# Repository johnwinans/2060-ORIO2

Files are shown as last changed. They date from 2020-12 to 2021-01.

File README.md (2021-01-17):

# ORIO2
Open Robot IO Controller Version 2 Rev 2.

A [PDF of the schematic can be found here](2060-ORIO2.pdf).

This project contains 
[KiCad 5](https://kicad.org/) 
design files for a 
[Rasbperry PI](https://www.raspberrypi.org/products/)
add-on module that can be used to operate a robot such as those used in 
[First Robotics Competition](https://www.firstinspires.org/robotics/frc).

The ORIO2 adds the following I/O ports to a Raspberry PI:

* 10 5V tolerant LVTTL quadrature inputs with 3.3v or 5v power
* 8 5V tolerant LVTTL digital inputs with 3.3v or 5v power
* 8 LVTTL digital outputs with 3.3v or 5v power
* 16 direct-FPGA GPIO pins on header with 3.3v power
* 1 Power LED
* 8 User LED outputs
* 8 User switch (binary inputs)
* 2 User push-button (binary inputs)
* 8 ADC inputs 0-5V (w/jumper on port 0 to monitor battery voltage)
* 16 PWM outputs w/6V, 3A power
* 1 12V RSL light output
* 8 24V solenoid outputs
* 1 12V air-compressor relay control output
* 1 Raspberry PI I2C pinout with 3.3V power supply & pullup resistors

All I/O is controlled with a Lattice ICE40HX4K-TQ144 FPGA that 
communicates with the PI using the PI's SPI port.

The FPGA and Raspberry PI source code is open-source and managed 
using a github repo here: 
[ORIO2-software](https://github.com/johnwinans/ORIO2-software)

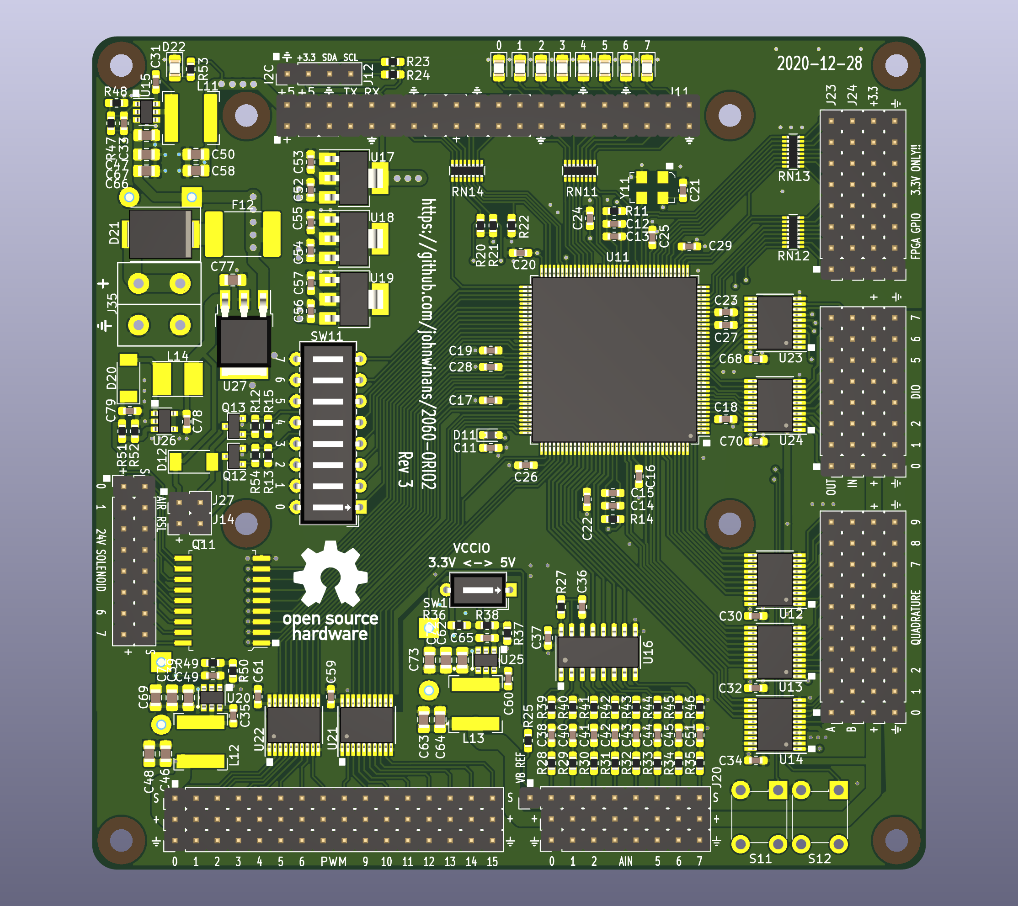
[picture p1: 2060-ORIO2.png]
PCB Image


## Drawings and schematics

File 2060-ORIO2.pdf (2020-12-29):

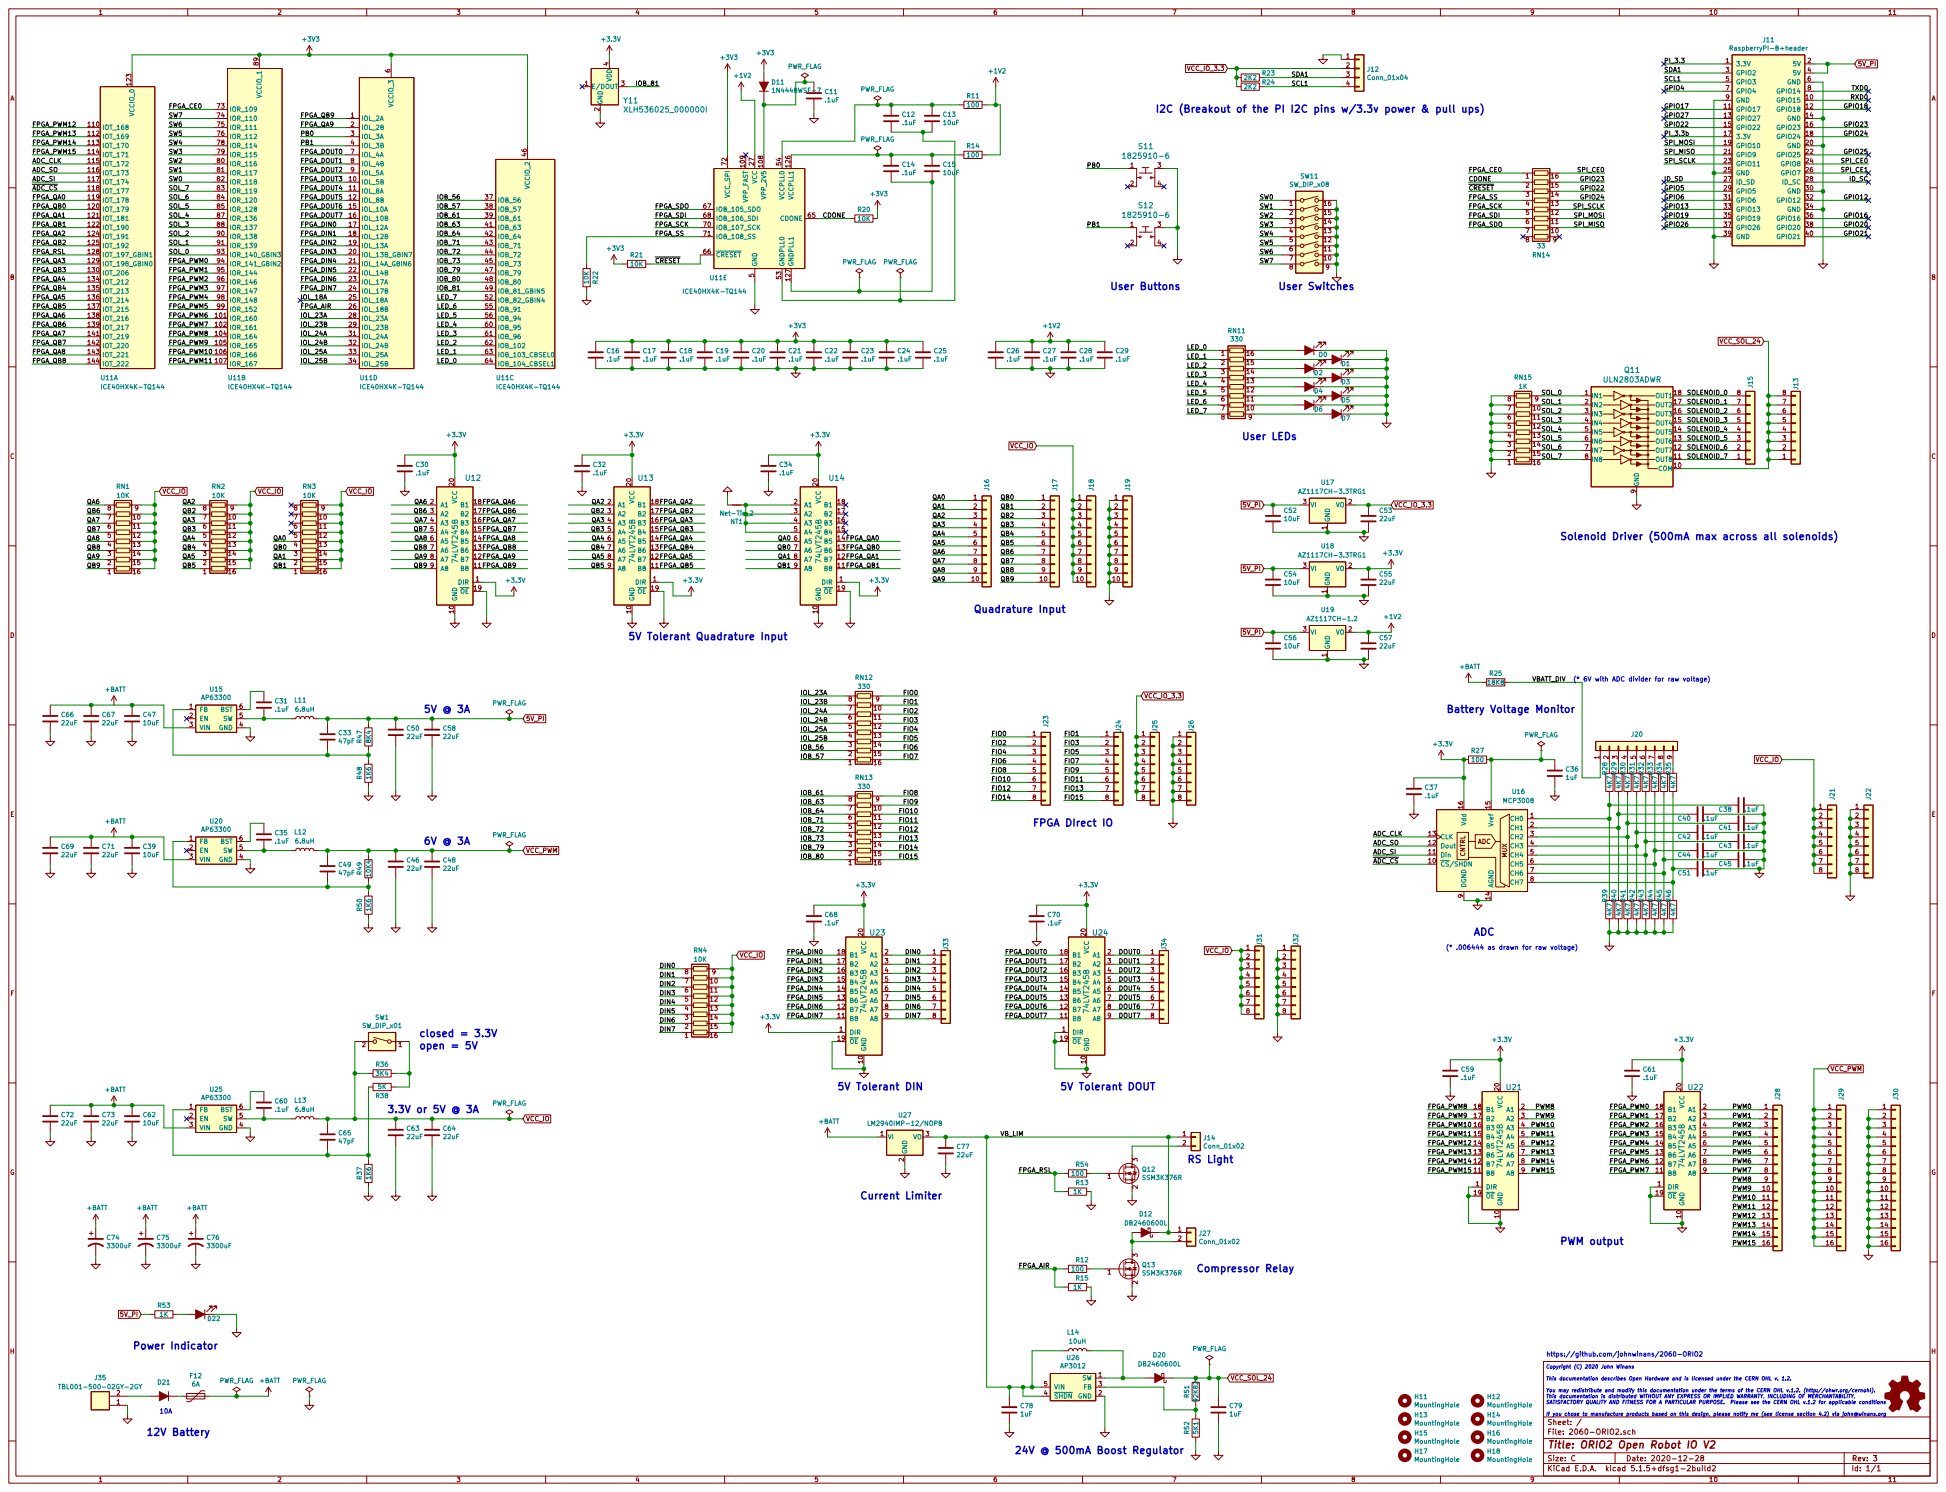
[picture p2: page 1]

I2C (Breakout of the PI I2C pins w/3.3v power & pull ups)

Solenoid Driver (500mA max across all solenoids)

(* 6V with ADC divider for raw voltage)

(* .006444 as drawn for raw voltage)

If you chose to manufacture products based on this design, please notify me (see license section 4.2) via john@winans.org Power Indicator

https://github.com/johnwinans/2060-ORIO2

Copyright (C) 2020 John Winans This documentation describes Open Hardware and is licensed under the CERN OHL v. 1.2. You may redistribute and modify this documentation under the terms of the CERN OHL v.1.2. (http://ohwr.org/cernohl). This documentation is distributed WITHOUT ANY EXPRESS OR IMPLIED WARRANTY, INCLUDING OF MERCHANTABILITY, SATISFACTORY QUALITY AND FITNESS FOR A PARTICULAR PURPOSE. Please see the CERN OHL v.1.2 for applicable conditions

H12 MountingHole H14 MountingHole H16 MountingHole H18 MountingHole

File: 2060-ORIO2.sch Sheet: /
Id: 1/1 Title: ORIO2 Open Robot IO V2

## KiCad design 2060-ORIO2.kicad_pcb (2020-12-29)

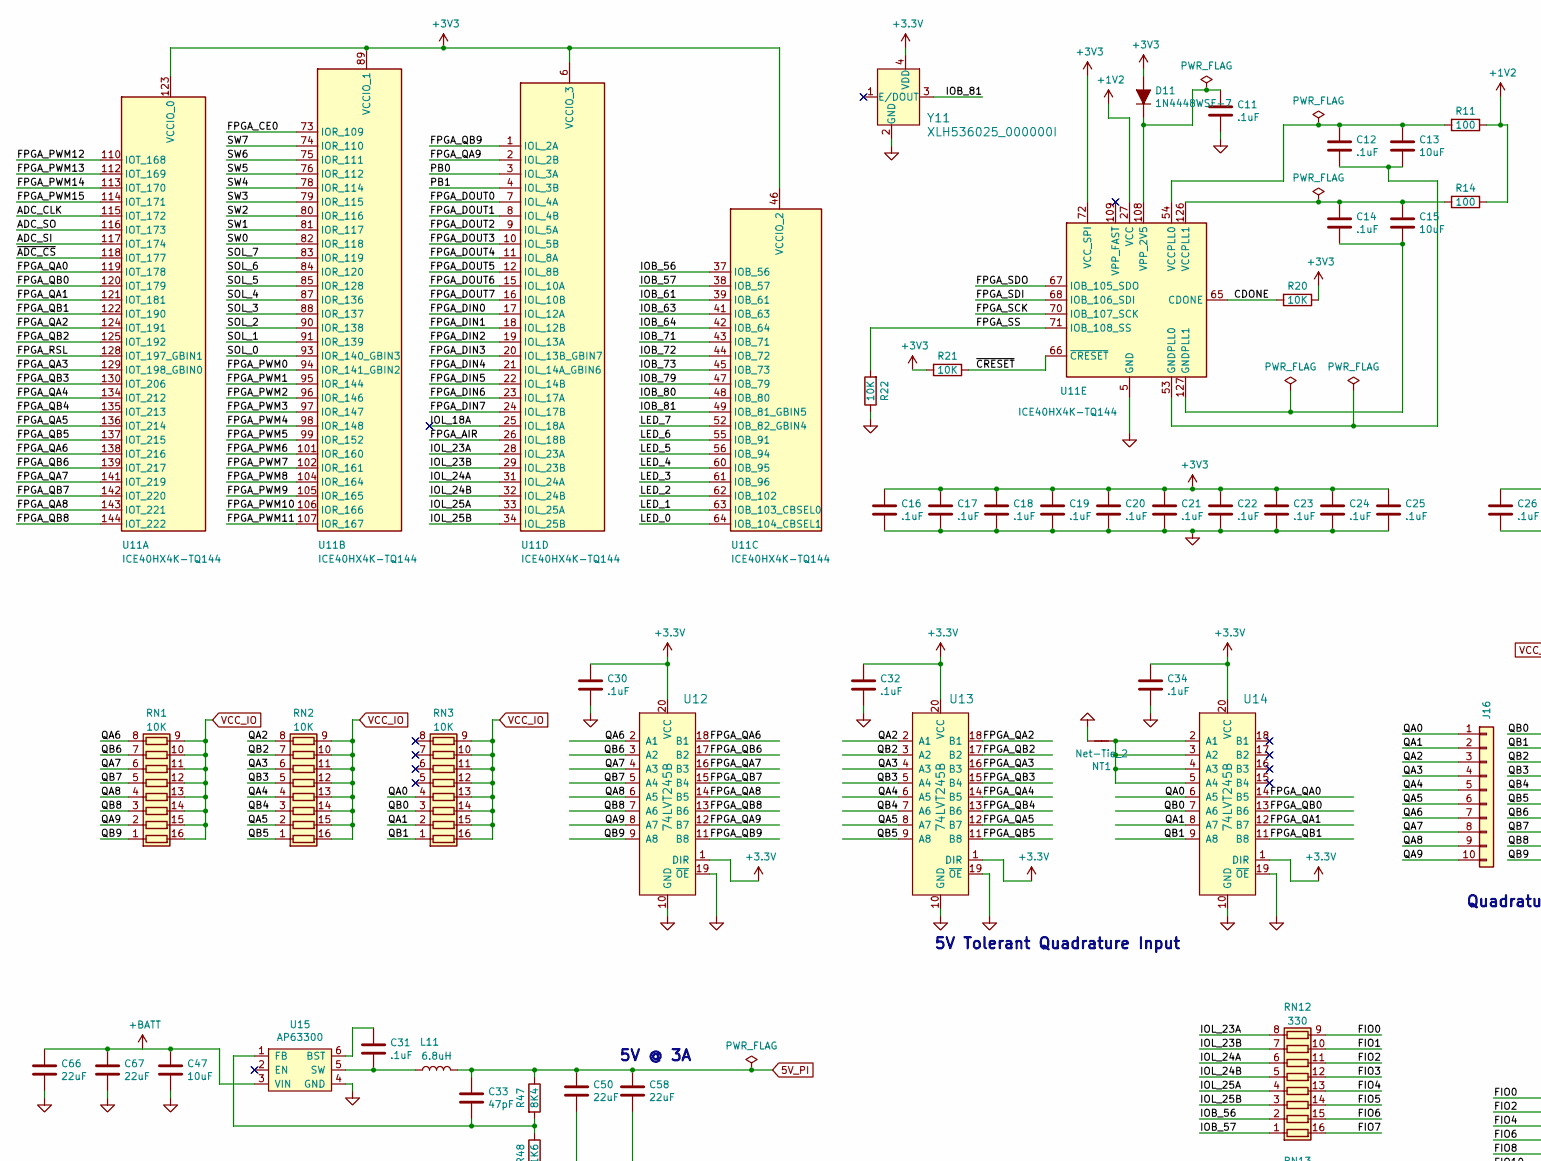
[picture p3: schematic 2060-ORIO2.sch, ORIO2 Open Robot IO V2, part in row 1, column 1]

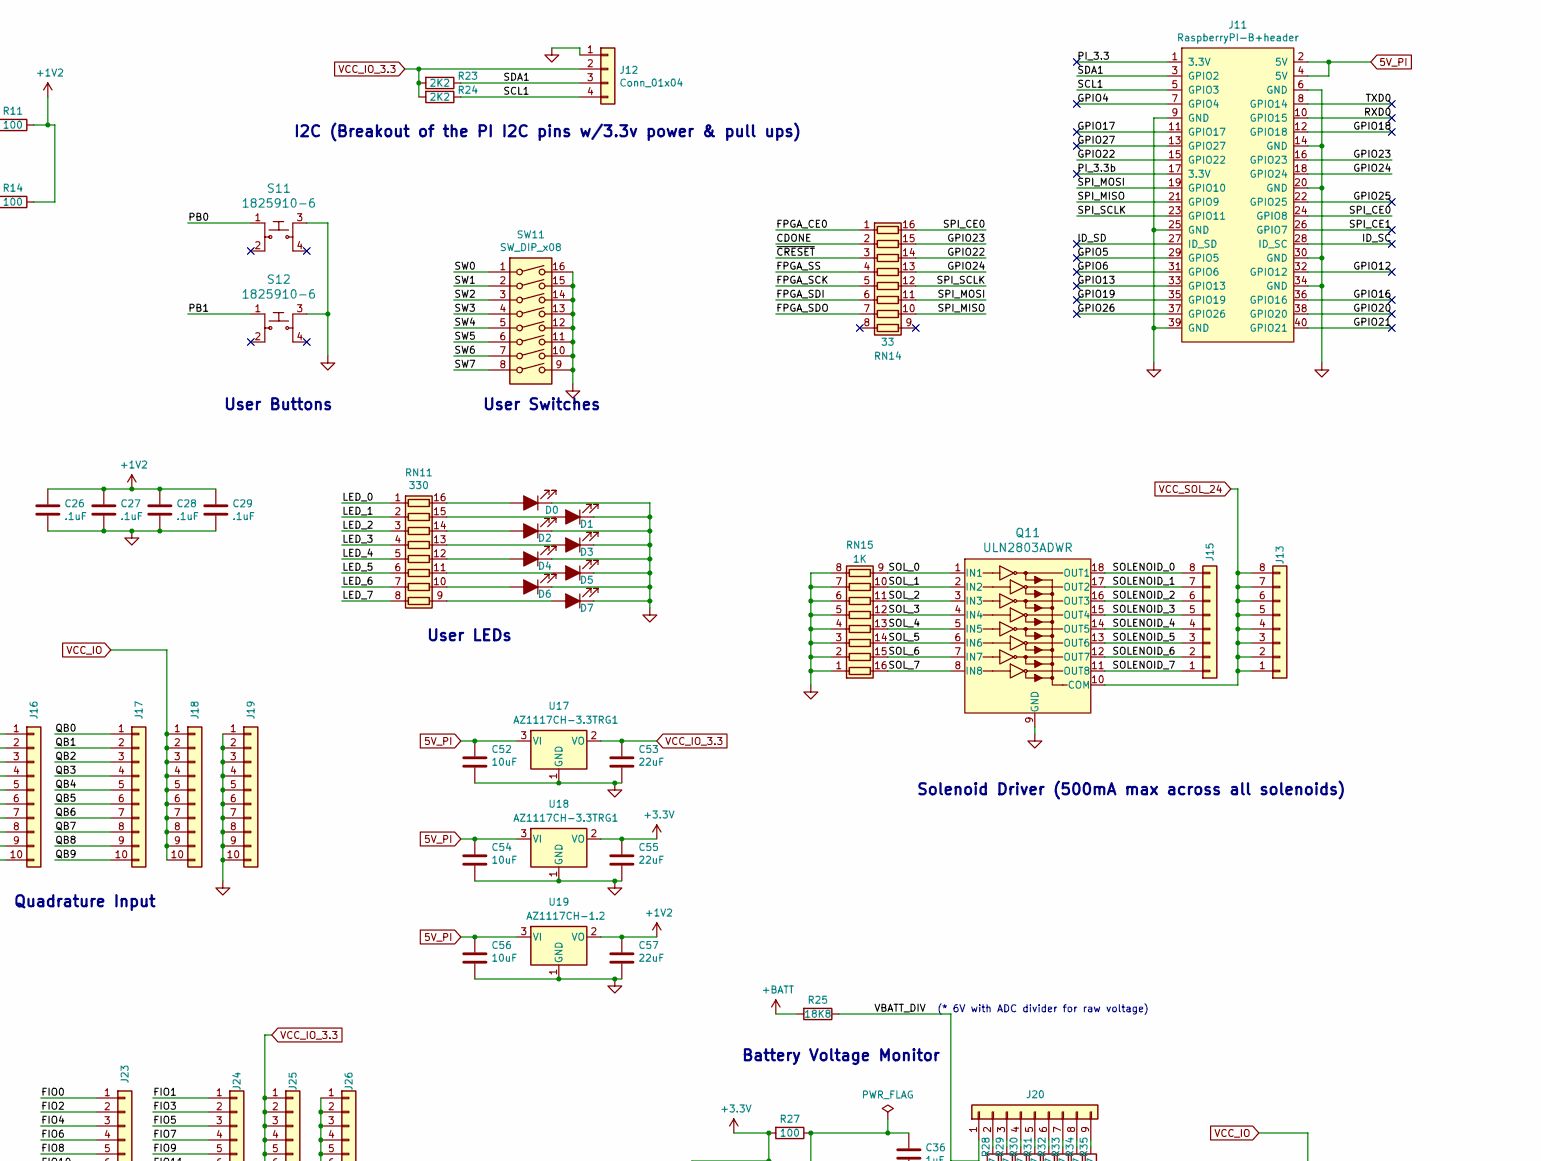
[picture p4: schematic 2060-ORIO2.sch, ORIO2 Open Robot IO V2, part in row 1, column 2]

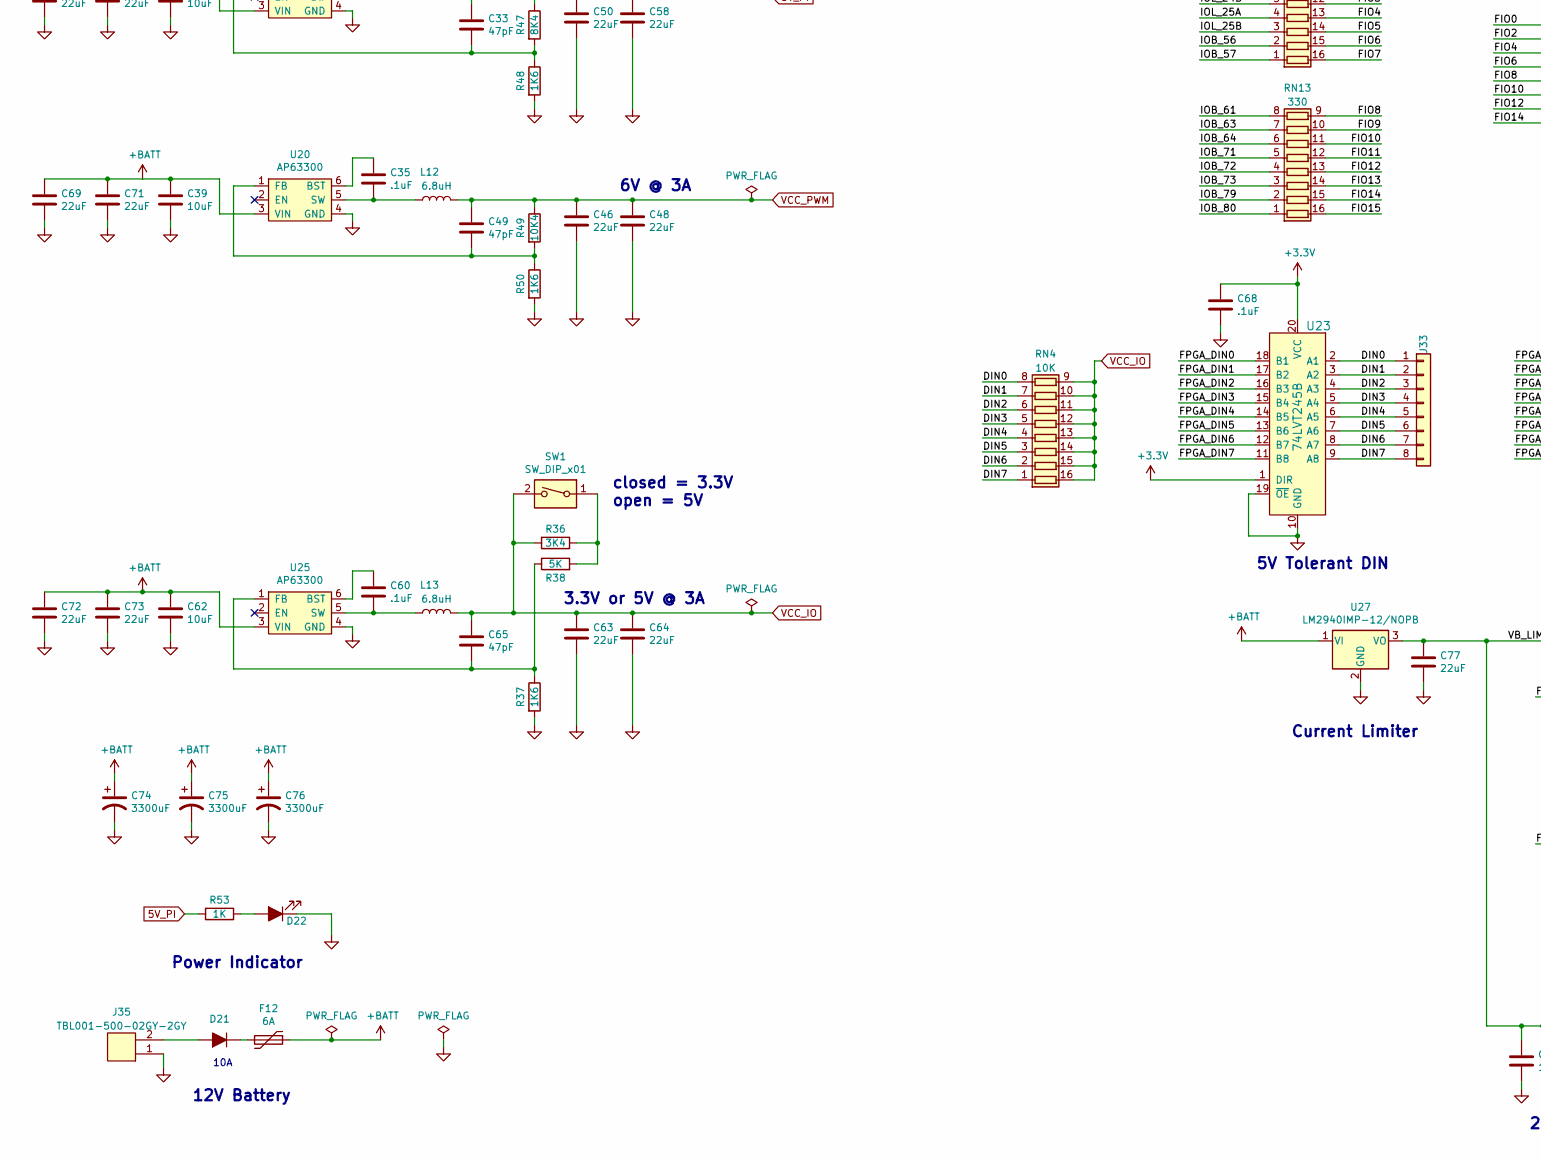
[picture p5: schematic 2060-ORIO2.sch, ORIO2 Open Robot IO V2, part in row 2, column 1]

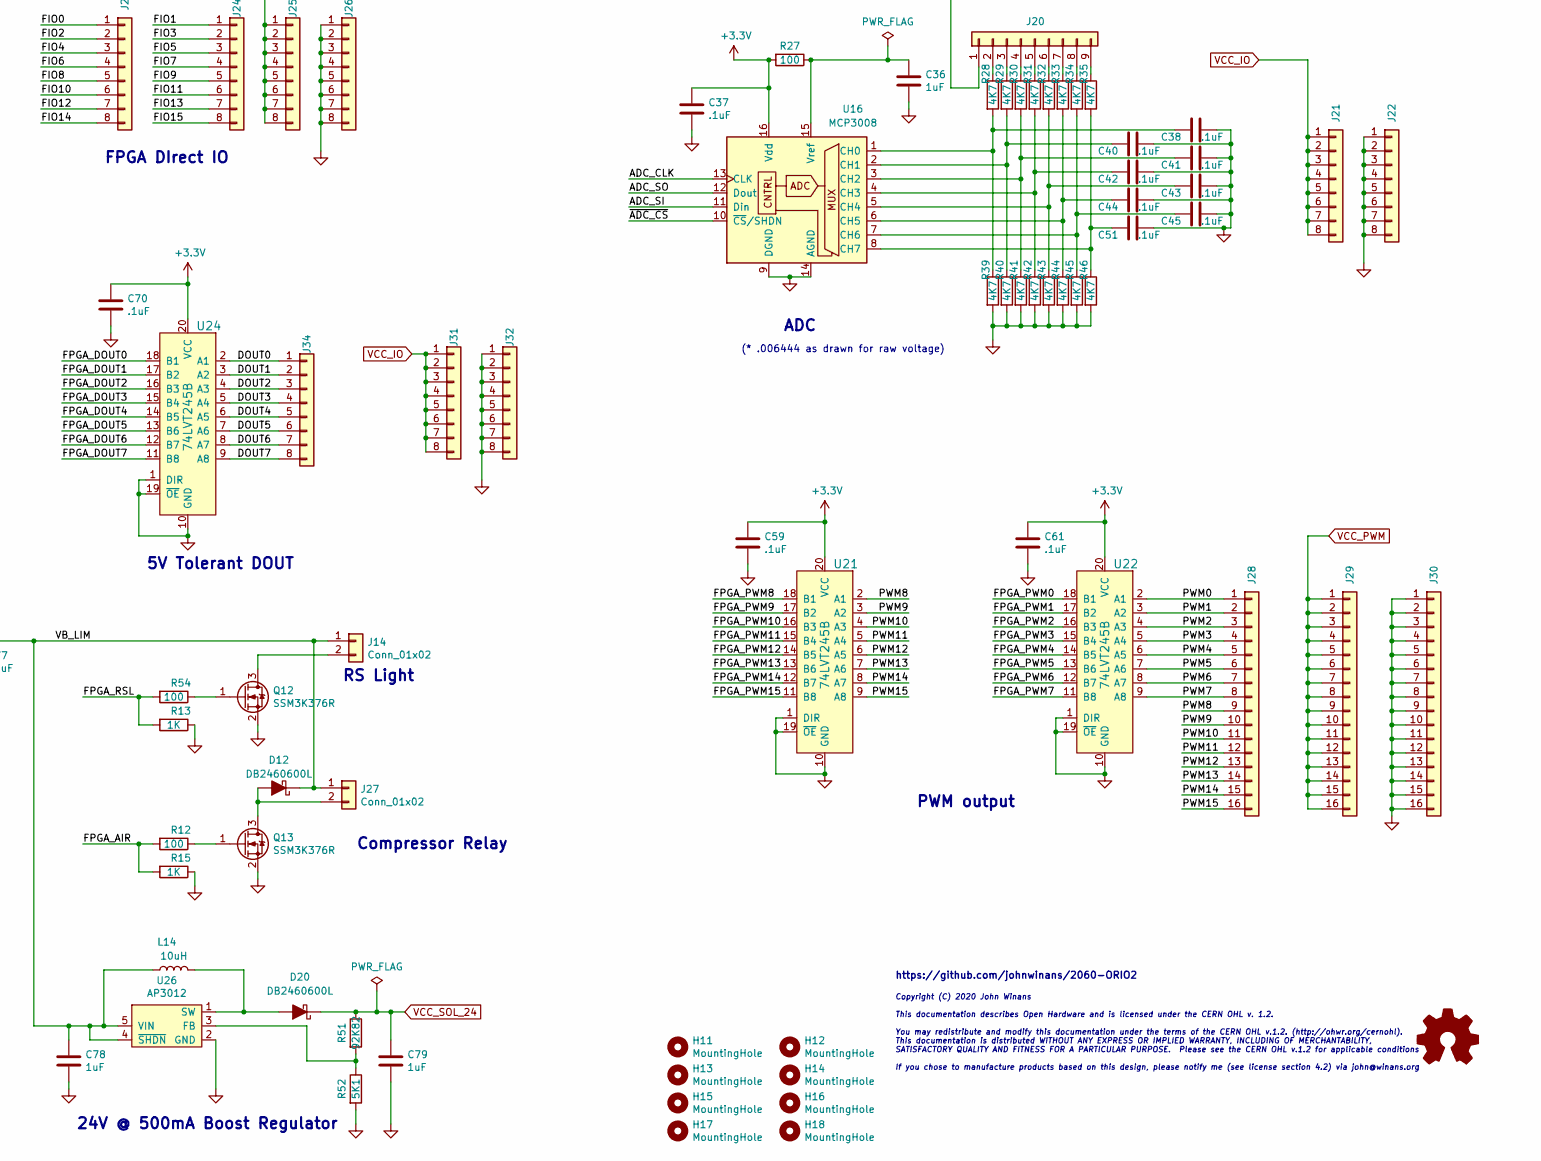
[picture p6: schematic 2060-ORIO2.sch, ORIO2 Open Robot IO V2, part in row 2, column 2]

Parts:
C11, C12, C14, C16, C17, C18, C19, C20, C21, C22, C23, C24, C25, C26, C27, C28, C29, C30, C31, C32, C34, C35, C37, C38, C40, C41, C42, C43, C44, C45, C51, C59, C60, C61, C68, C70: .1uF; C_0603_1608Metric_Pad1.05x0.95mm_HandSolder; MPN C1608X5R1E104K; Digi-Key_PN 445-6854-1-ND
C13, C15, C52, C54, C56: 10uF; C_0603_1608Metric_Pad1.05x0.95mm_HandSolder; MPN CL10A106MQ8NNNC; Digi-Key_PN 1276-1119-1-ND
C33, C49, C65: 47pF; C_0603_1608Metric_Pad1.05x0.95mm_HandSolder
C36, C78, C79: 1uF; C_0603_1608Metric_Pad1.05x0.95mm_HandSolder; MPN CL10A105KA8NNNC; Digi-Key_PN 1276-1102-1-ND
C39, C47, C62: 10uF; C_0805_2012Metric_Pad1.15x1.40mm_HandSolder
C46, C48, C50, C58, C63, C64: 22uF; C_0805_2012Metric_Pad1.15x1.40mm_HandSolder; MPN GRM21BR61A226ME44L; Digi-Key_PN 490-10746-1-ND
C53, C55, C57: 22uF; C_0603_1608Metric_Pad1.05x0.95mm_HandSolder; MPN CL10A226MQ8NRNE; Digi-Key_PN 1276-2868-1-ND
C66, C67, C69, C71, C72, C73, C77: 22uF; C_0805_2012Metric_Pad1.15x1.40mm_HandSolder; Digi-Key_PN 490-14661-1-ND
C74, C75, C76: 3300uF; CP_Radial_D16.0mm_P7.50mm; MPN UVR1E332MHD; Digi-Key_PN 493-1067-ND
D0, D1, D2, D3, D4, D5, D6, D7, D22: LED_ALT; LED_0805_2012Metric_Pad1.15x1.40mm_HandSolder; MPN LG R971-KN-1; Digi-Key_PN 475-1410-1-ND
D11: 1N4448WSF-7; D_0603_1608Metric_Pad1.05x0.95mm_HandSolder; MPN 1N4448HWS-7-F; Digi-Key_PN 1N4448HWS-FDICT-ND
D12, D20: DB2460600L; D_SOD-128; MPN DB2460600L; Digi-Key_PN DB2460600LCT-ND
D21: D_ALT; D_SMC; MPN S10KC V7G; Digi-Key_PN S10KCV7GCT-ND
F12: 6A; Fuse_2920_7451Metric_Pad2.10x5.45mm_HandSolder; MPN 2920L600/12MR; Digi-Key_PN F8137CT-ND
H11, H12, H13, H14, H15, H16, H17, H18: MountingHole; MountingHole_2.7mm_M2.5; MPN x; Digi-Key_PN x
J11: RaspberryPI-B+header; PinHeader_2x20_P2.54mm_Vertical; MPN x; Digi-Key_PN x
J12: Conn_01x04; PinHeader_1x04_P2.54mm_Vertical; MPN x; Digi-Key_PN x
J13, J15, J21, J22, J23, J24, J25, J26, J31, J32, J33, J34: Conn_01x08; PinHeader_1x08_P2.54mm_Vertical; MPN x; Digi-Key_PN x
J14, J27: Conn_01x02; PinHeader_1x02_P2.54mm_Vertical; MPN x; Digi-Key_PN x
J16, J17, J18, J19: Conn_01x10; PinHeader_1x10_P2.54mm_Vertical; MPN x; Digi-Key_PN x
J20: Conn_01x09; PinHeader_1x09_P2.54mm_Vertical; MPN x; Digi-Key_PN x
J28, J29, J30: Conn_01x16; PinHeader_1x16_P2.54mm_Vertical; MPN x; Digi-Key_PN x
J35: TBL001-500-02GY-2GY; MPN TBL001-500-02GY-2GY; Digi-Key_PN 102-6360-ND
L11, L12, L13: 6.8uH; L_Bourns-SRN6028; MPN VLS6045EX-6R8M; Digi-Key_PN 445-173057-1-ND
L14: 10uH; L_Taiyo-Yuden_NR-40xx_HandSoldering; MPN NRG4026T100M; Digi-Key_PN 587-2376-1-ND
LOGO11: Logo_Open_Hardware_Small; OSHW-Logo_11.4x12mm_SilkScreen; MPN x; Digi-Key_PN x
NT1: Net-Tie_2; NetTie-2_SMD_Pad0.5mm; MPN x; Digi-Key_PN x
Q11: ULN2803ADWR; SOIC-18_W7.5mm; MPN ULN2803ADWR; Digi-Key_PN 296-15777-1-ND
Q12, Q13: SSM3K376R; SOT-23; MPN ‎SSM3K376R,LF; Digi-Key_PN SSM3K376RLFCT-ND‎
R11, R14, R27: 100; R_0603_1608Metric_Pad1.05x0.95mm_HandSolder; MPN RC0603FR-07100RL; Digi-Key_PN 311-100HRCT-ND
R12, R54: 100; R_0603_1608Metric_Pad0.98x0.95mm_HandSolder; MPN RC0603FR-07100RL; Digi-Key_PN 311-100HRCT-ND
R13, R15: 1K; R_0603_1608Metric_Pad0.98x0.95mm_HandSolder
R20, R21, R22: 10K; R_0603_1608Metric_Pad1.05x0.95mm_HandSolder; MPN RC0603FR-0710KL; Digi-Key_PN 311-10.0KHRCT-ND
R23, R24: 2K2; R_0603_1608Metric_Pad1.05x0.95mm_HandSolder; MPN RC0603FR-072K2L; Digi-Key_PN 311-2.20KHRCT-ND
R25: 18K8; R_0603_1608Metric_Pad1.05x0.95mm_HandSolder; MPN RC0603FR-0718KL; Digi-Key_PN 311-18.0KHRCT-ND
R28, R29, R30, R31, R32, R33, R34, R35, R39, R40, R41, R42, R43, R44, R45, R46: 4K7; R_0603_1608Metric_Pad1.05x0.95mm_HandSolder; MPN RC0603FR-074K7L; Digi-Key_PN 311-4.70KHRCT-ND
R36: 3K4; R_0603_1608Metric_Pad1.05x0.95mm_HandSolder; MPN RMCF0603FT3K40; Digi-Key_PN RMCF0603FT3K40CT-ND
R37, R48, R50: 1K6; R_0603_1608Metric_Pad1.05x0.95mm_HandSolder; MPN RMCF0603FT1K60; Digi-Key_PN RMCF0603FT1K60CT-ND
R38: 5K; R_0603_1608Metric_Pad1.05x0.95mm_HandSolder; MPN CR0603-FX-5101ELF; Digi-Key_PN CR0603-FX-5101ELFCT-ND
R47: 8K4; R_0603_1608Metric_Pad1.05x0.95mm_HandSolder; MPN RMCF0603FT8K45; Digi-Key_PN RMCF0603FT8K45CT-ND
R49: 10K4; R_0603_1608Metric_Pad1.05x0.95mm_HandSolder; MPN RMCF0603FT10K5; Digi-Key_PN RMCF0603FT10K5CT-ND
R51: 92K82; R_0603_1608Metric_Pad1.05x0.95mm_HandSolder; MPN RMCF0603FT90K9; Digi-Key_PN RMCF0603FT90K9CT-ND
R52: 5K1; R_0603_1608Metric_Pad1.05x0.95mm_HandSolder; MPN CR0603-FX-5101ELF; Digi-Key_PN CR0603-FX-5101ELFCT-ND
R53: 1K; R_0603_1608Metric_Pad1.05x0.95mm_HandSolder; MPN RC0603FR-071KL; Digi-Key_PN 311-1.00KHRCT-ND
RN1, RN2, RN3, RN4: 10K; R_Array_Convex_8x0602; MPN EXB-2HV103JV; Digi-Key_PN Y1103CT-ND
RN11, RN12, RN13: 330; R_Array_Convex_8x0602; MPN EXB-2HV331JV; Digi-Key_PN Y1331CT-ND
RN14: 33; R_Array_Convex_8x0602; MPN EXB-2HV330JV; Digi-Key_PN Y1330CT-ND
RN15: 1K; R_Array_Convex_8x0602; MPN EXB-2HV102JV; Digi-Key_PN Y1102CT-ND
S11, S12: 1825910-6; Switch_Tactile_THT_6x6mm; MPN 1825910-6; Digi-Key_PN 450-1650-ND
SW1: SW_DIP_x01; SW_DIP_SPSTx01_Slide_6.7x4.1mm_W7.62mm_P2.54mm_LowProfile; MPN DS04-254-1L-01BK; Digi-Key_PN 2223-DS04-254-1L-01BK-ND
SW11: SW_DIP_x08; SW_DIP_SPSTx08_Slide_6.7x21.88mm_W7.62mm_P2.54mm_LowProfile; MPN 210-8MS; Digi-Key_PN CT2108MS-ND
U11: ICE40HX4K-TQ144; TQFP-144_20x20mm_P0.5mm; MPN ICE40HX4K-TQ144; Digi-Key_PN 220-1572-ND
U12, U13, U14, U21, U22, U23, U24: ‎74LVT245B; TSSOP-20_4.4x6.5mm_P0.65mm; MPN 74LVT245BPW,118; Digi-Key_PN 1727-6005-1-ND
U15, U20, U25: AP63300; SOT-23-6; MPN AP63300WU-7; Digi-Key_PN 31-AP63300WU-7CT-ND
U16: MCP3008; SOIC-16_3.9x9.9mm_P1.27mm; MPN MCP3008-I/SL; Digi-Key_PN MCP3008-I/SL-ND
U17, U18: AZ1117CH-3.3TRG1; SOT-223-3_TabPin2; MPN AZ1117CH-3.3TRG1; Digi-Key_PN AZ1117CH-3.3TRG1DICT-ND
U19: AZ1117CH-1.2; SOT-223-3_TabPin2; MPN AZ1117CH-1.2TRG1; Digi-Key_PN AZ1117CH-1.2TRG1DICT-ND
U26: AP3012; SOT-23-5; MPN AP3012KTR-G1; Digi-Key_PN AP3012KTR-G1DICT-ND
U27: LM2940IMP-12/NOPB; TO-252-3_TabPin2; MPN LM2940IMP-12/NOPB; Digi-Key_PN LM2940IMP-12/NOPBCT-ND
Y11: XLH536025_000000I; Oscillator_XLH536025.000000I; MPN XLH536025.000000I; Digi-Key_PN 631-1156-1-ND

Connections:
5V_PI: C33.1, C50.1, C52.1, C54.1, C56.1, C58.1, J11.2 (5V), J11.4 (5V), L11.2, R47.1, R53.2, U17.3 (VI), U18.3 (VI), U19.3 (VI)
+1V2: C26.1, C27.1, C28.1, C29.1, C57.1, R11.1, R14.1, U11.27 (VCC), U11.40 (VCC), U11.92 (VCC), U11.111 (VCC), U19.2 (VO)
+BATT: C39.1, C47.1, C62.1, C66.1, C67.1, C69.1, C71.1, C72.1, C73.1, C74.1, C75.1, C76.1, F12.1, R25.2, U15.3 (VIN), U20.3 (VIN), U25.3 (VIN), U27.1 (VI)
/ADC_CLK: U11.115 (IOT_172), U16.13 (CLK)
/ADC_SI: U11.117 (IOT_174), U16.11 (Din)
/ADC_SO: U11.116 (IOT_173), U16.12 (Dout)
/CDONE: R20.2, RN14.2 (R2.1), U11.65 (CDONE)
/DIN0: J33.1, RN4.8 (R8.1), U23.2 (A1)
/DIN1: J33.2, RN4.7 (R7.1), U23.3 (A2)
/DIN2: J33.3, RN4.6 (R6.1), U23.4 (A3)
/DIN3: J33.4, RN4.5 (R5.1), U23.5 (A4)
/DIN4: J33.5, RN4.4 (R4.1), U23.6 (A5)
/DIN5: J33.6, RN4.3 (R3.1), U23.7 (A6)
/DIN6: J33.7, RN4.2 (R2.1), U23.8 (A7)
/DIN7: J33.8, RN4.1 (R1.1), U23.9 (A8)
/DOUT0: J34.1, U24.2 (A1)
/DOUT1: J34.2, U24.3 (A2)
/DOUT2: J34.3, U24.4 (A3)
/DOUT3: J34.4, U24.5 (A4)
/DOUT4: J34.5, U24.6 (A5)
/DOUT5: J34.6, U24.7 (A6)
/DOUT6: J34.7, U24.8 (A7)
/DOUT7: J34.8, U24.9 (A8)
/FIO0: J23.1, RN12.9 (R8.2)
/FIO1: J24.1, RN12.10 (R7.2)
/FIO2: J23.2, RN12.11 (R6.2)
/FIO3: J24.2, RN12.12 (R5.2)
/FIO4: J23.3, RN12.13 (R4.2)
/FIO5: J24.3, RN12.14 (R3.2)
/FIO6: J23.4, RN12.15 (R2.2)
/FIO7: J24.4, RN12.16 (R1.2)
/FIO8: J23.5, RN13.9 (R8.2)
/FIO9: J24.5, RN13.10 (R7.2)
/FIO10: J23.6, RN13.11 (R6.2)
/FIO11: J24.6, RN13.12 (R5.2)
/FIO12: J23.7, RN13.13 (R4.2)
/FIO13: J24.7, RN13.14 (R3.2)
/FIO14: J23.8, RN13.15 (R2.2)
/FIO15: J24.8, RN13.16 (R1.2)
/FPGA_AIR: R12.2, R15.2, U11.26 (IOL_18B)
/FPGA_CE0: RN14.1 (R1.1), U11.73 (IOR_109)
/FPGA_DIN0: U11.17 (IOL_12A), U23.18 (B1)
/FPGA_DIN1: U11.18 (IOL_12B), U23.17 (B2)
/FPGA_DIN2: U11.19 (IOL_13A), U23.16 (B3)
/FPGA_DIN3: U11.20 (IOL_13B_GBIN7), U23.15 (B4)
/FPGA_DIN4: U11.21 (IOL_14A_GBIN6), U23.14 (B5)
/FPGA_DIN5: U11.22 (IOL_14B), U23.13 (B6)
/FPGA_DIN6: U11.23 (IOL_17A), U23.12 (B7)
/FPGA_DIN7: U11.24 (IOL_17B), U23.11 (B8)
/FPGA_DOUT0: U11.7 (IOL_4A), U24.18 (B1)
/FPGA_DOUT1: U11.8 (IOL_4B), U24.17 (B2)
/FPGA_DOUT2: U11.9 (IOL_5A), U24.16 (B3)
/FPGA_DOUT3: U11.10 (IOL_5B), U24.15 (B4)
/FPGA_DOUT4: U11.11 (IOL_8A), U24.14 (B5)
/FPGA_DOUT5: U11.12 (IOL_8B), U24.13 (B6)
/FPGA_DOUT6: U11.15 (IOL_10A), U24.12 (B7)
/FPGA_DOUT7: U11.16 (IOL_10B), U24.11 (B8)
/FPGA_PWM0: U11.94 (IOR_141_GBIN2), U22.18 (B1)
/FPGA_PWM1: U11.95 (IOR_144), U22.17 (B2)
/FPGA_PWM2: U11.96 (IOR_146), U22.16 (B3)
/FPGA_PWM3: U11.97 (IOR_147), U22.15 (B4)
/FPGA_PWM4: U11.98 (IOR_148), U22.14 (B5)
/FPGA_PWM5: U11.99 (IOR_152), U22.13 (B6)
/FPGA_PWM6: U11.101 (IOR_160), U22.12 (B7)
/FPGA_PWM7: U11.102 (IOR_161), U22.11 (B8)
/FPGA_PWM8: U11.104 (IOR_164), U21.18 (B1)
/FPGA_PWM9: U11.105 (IOR_165), U21.17 (B2)
/FPGA_PWM10: U11.106 (IOR_166), U21.16 (B3)
/FPGA_PWM11: U11.107 (IOR_167), U21.15 (B4)
/FPGA_PWM12: U11.110 (IOT_168), U21.14 (B5)
/FPGA_PWM13: U11.112 (IOT_169), U21.13 (B6)
/FPGA_PWM14: U11.113 (IOT_170), U21.12 (B7)
/FPGA_PWM15: U11.114 (IOT_171), U21.11 (B8)
/FPGA_QA0: U11.119 (IOT_178), U14.14 (B5)
/FPGA_QA1: U11.121 (IOT_181), U14.12 (B7)
/FPGA_QA2: U11.124 (IOT_191), U13.18 (B1)
/FPGA_QA3: U11.129 (IOT_198_GBIN0), U13.16 (B3)
/FPGA_QA4: U11.134 (IOT_212), U13.14 (B5)
/FPGA_QA5: U11.136 (IOT_214), U13.12 (B7)
/FPGA_QA6: U11.138 (IOT_216), U12.18 (B1)
/FPGA_QA7: U11.141 (IOT_219), U12.16 (B3)
/FPGA_QA8: U11.143 (IOT_221), U12.14 (B5)
/FPGA_QA9: U11.2 (IOL_2B), U12.12 (B7)
/FPGA_QB0: U11.120 (IOT_179), U14.13 (B6)
/FPGA_QB1: U11.122 (IOT_190), U14.11 (B8)
/FPGA_QB2: U11.125 (IOT_192), U13.17 (B2)
/FPGA_QB3: U11.130 (IOT_206), U13.15 (B4)
/FPGA_QB4: U11.135 (IOT_213), U13.13 (B6)
/FPGA_QB5: U11.137 (IOT_215), U13.11 (B8)
/FPGA_QB6: U11.139 (IOT_217), U12.17 (B2)
/FPGA_QB7: U11.142 (IOT_220), U12.15 (B4)
/FPGA_QB8: U11.144 (IOT_222), U12.13 (B6)
/FPGA_QB9: U11.1 (IOL_2A), U12.11 (B8)
/FPGA_RSL: R13.2, R54.2, U11.128 (IOT_197_GBIN1)
/FPGA_SCK: RN14.5 (R5.1), U11.70 (IOB_107_SCK)
/FPGA_SDI: RN14.6 (R6.1), U11.68 (IOB_106_SDI)
/FPGA_SDO: RN14.7 (R7.1), U11.67 (IOB_105_SDO)
/FPGA_SS: R22.2, RN14.4 (R4.1), U11.71 (IOB_108_SS)
/GPIO4: J11.7 (GPIO4)
/GPIO5: J11.29 (GPIO5)
/GPIO6: J11.31 (GPIO6)
/GPIO12: J11.32 (GPIO12)
/GPIO13: J11.33 (GPIO13)
/GPIO16: J11.36 (GPIO16)
/GPIO17: J11.11 (GPIO17)
/GPIO18: J11.12 (GPIO18)
/GPIO19: J11.35 (GPIO19)
/GPIO20: J11.38 (GPIO20)
/GPIO21: J11.40 (GPIO21)
/GPIO22: J11.15 (GPIO22), RN14.14 (R3.2)
/GPIO23: J11.16 (GPIO23), RN14.15 (R2.2)
/GPIO24: J11.18 (GPIO24), RN14.13 (R4.2)
/GPIO25: J11.22 (GPIO25)
/GPIO26: J11.37 (GPIO26)
/GPIO27: J11.13 (GPIO27)
/ID_SC: J11.28 (ID_SC)
/ID_SD: J11.27 (ID_SD)
/IOB_56: RN12.2 (R2.1), U11.37 (IOB_56)
/IOB_57: RN12.1 (R1.1), U11.38 (IOB_57)
/IOB_61: RN13.8 (R8.1), U11.39 (IOB_61)
/IOB_63: RN13.7 (R7.1), U11.41 (IOB_63)
/IOB_64: RN13.6 (R6.1), U11.42 (IOB_64)
/IOB_71: RN13.5 (R5.1), U11.43 (IOB_71)
/IOB_72: RN13.4 (R4.1), U11.44 (IOB_72)
/IOB_73: RN13.3 (R3.1), U11.45 (IOB_73)
/IOB_79: RN13.2 (R2.1), U11.47 (IOB_79)
/IOB_80: RN13.1 (R1.1), U11.48 (IOB_80)
/IOB_81: U11.49 (IOB_81_GBIN5), Y11.3 (OUT)
/IOL_18A: U11.25 (IOL_18A)
/IOL_23A: RN12.8 (R8.1), U11.28 (IOL_23A)
/IOL_23B: RN12.7 (R7.1), U11.29 (IOL_23B)
/IOL_24A: RN12.6 (R6.1), U11.31 (IOL_24A)
/IOL_24B: RN12.5 (R5.1), U11.32 (IOL_24B)
/IOL_25A: RN12.4 (R4.1), U11.33 (IOL_25A)
/IOL_25B: RN12.3 (R3.1), U11.34 (IOL_25B)
/LED_0: RN11.1 (R1.1), U11.64 (IOB_104_CBSEL1)
/LED_1: RN11.2 (R2.1), U11.63 (IOB_103_CBSEL0)
/LED_2: RN11.3 (R3.1), U11.62 (IOB_102)
/LED_3: RN11.4 (R4.1), U11.61 (IOB_96)
/LED_4: RN11.5 (R5.1), U11.60 (IOB_95)
/LED_5: RN11.6 (R6.1), U11.56 (IOB_94)
/LED_6: RN11.7 (R7.1), U11.55 (IOB_91)
/LED_7: RN11.8 (R8.1), U11.52 (IOB_82_GBIN4)
/PB0: S11.1, U11.3 (IOL_3A)
/PB1: S12.1, U11.4 (IOL_3B)
/PI_3.3: J11.1 (3.3V)
/PI_3.3b: J11.17 (3.3V)
/PWM0: J28.1, U22.2 (A1)
/PWM1: J28.2, U22.3 (A2)
/PWM2: J28.3, U22.4 (A3)
/PWM3: J28.4, U22.5 (A4)
/PWM4: J28.5, U22.6 (A5)
/PWM5: J28.6, U22.7 (A6)
/PWM6: J28.7, U22.8 (A7)
/PWM7: J28.8, U22.9 (A8)
/PWM8: J28.9, U21.2 (A1)
/PWM9: J28.10, U21.3 (A2)
/PWM10: J28.11, U21.4 (A3)
/PWM11: J28.12, U21.5 (A4)
/PWM12: J28.13, U21.6 (A5)
/PWM13: J28.14, U21.7 (A6)
/PWM14: J28.15, U21.8 (A7)
/PWM15: J28.16, U21.9 (A8)
/QA0: J16.1, RN3.4 (R4.1), U14.6 (A5)
/QA1: J16.2, RN3.2 (R2.1), U14.8 (A7)
/QA2: J16.3, RN2.8 (R8.1), U13.2 (A1)
/QA3: J16.4, RN2.6 (R6.1), U13.4 (A3)
/QA4: J16.5, RN2.4 (R4.1), U13.6 (A5)
/QA5: J16.6, RN2.2 (R2.1), U13.8 (A7)
/QA6: J16.7, RN1.8 (R8.1), U12.2 (A1)
/QA7: J16.8, RN1.6 (R6.1), U12.4 (A3)
/QA8: J16.9, RN1.4 (R4.1), U12.6 (A5)
/QA9: J16.10, RN1.2 (R2.1), U12.8 (A7)
/QB0: J17.1, RN3.3 (R3.1), U14.7 (A6)
/QB1: J17.2, RN3.1 (R1.1), U14.9 (A8)
/QB2: J17.3, RN2.7 (R7.1), U13.3 (A2)
/QB3: J17.4, RN2.5 (R5.1), U13.5 (A4)
/QB4: J17.5, RN2.3 (R3.1), U13.7 (A6)
/QB5: J17.6, RN2.1 (R1.1), U13.9 (A8)
/QB6: J17.7, RN1.7 (R7.1), U12.3 (A2)
/QB7: J17.8, RN1.5 (R5.1), U12.5 (A4)
/QB8: J17.9, RN1.3 (R3.1), U12.7 (A6)
/QB9: J17.10, RN1.1 (R1.1), U12.9 (A8)
/RXD0: J11.10 (GPIO15)
/SCL1: J11.5 (GPIO3), J12.4, R24.1
/SDA1: J11.3 (GPIO2), J12.3, R23.1
/SOLENOID_0: J15.8, Q11.18 (OUT1)
/SOLENOID_1: J15.7, Q11.17 (OUT2)
/SOLENOID_2: J15.6, Q11.16 (OUT3)
/SOLENOID_3: J15.5, Q11.15 (OUT4)
/SOLENOID_4: J15.4, Q11.14 (OUT5)
/SOLENOID_5: J15.3, Q11.13 (OUT6)
/SOLENOID_6: J15.2, Q11.12 (OUT7)
/SOLENOID_7: J15.1, Q11.11 (OUT8)
/SOL_0: Q11.1 (IN1), RN15.9 (R8.2), U11.93 (IOR_140_GBIN3)
/SOL_1: Q11.2 (IN2), RN15.10 (R7.2), U11.91 (IOR_139)
/SOL_2: Q11.3 (IN3), RN15.11 (R6.2), U11.90 (IOR_138)
/SOL_3: Q11.4 (IN4), RN15.12 (R5.2), U11.88 (IOR_137)
/SOL_4: Q11.5 (IN5), RN15.13 (R4.2), U11.87 (IOR_136)
/SOL_5: Q11.6 (IN6), RN15.14 (R3.2), U11.85 (IOR_128)
/SOL_6: Q11.7 (IN7), RN15.15 (R2.2), U11.84 (IOR_120)
/SOL_7: Q11.8 (IN8), RN15.16 (R1.2), U11.83 (IOR_119)
/SPI_CE0: J11.24 (GPIO8), RN14.16 (R1.2)
/SPI_CE1: J11.26 (GPIO7)
/SPI_MISO: J11.21 (GPIO9), RN14.10 (R7.2)
/SPI_MOSI: J11.19 (GPIO10), RN14.11 (R6.2)
/SPI_SCLK: J11.23 (GPIO11), RN14.12 (R5.2)
/SW0: SW11.1, U11.82 (IOR_118)
/SW1: SW11.2, U11.81 (IOR_117)
/SW2: SW11.3, U11.80 (IOR_116)
/SW3: SW11.4, U11.79 (IOR_115)
/SW4: SW11.5, U11.78 (IOR_114)
/SW5: SW11.6, U11.76 (IOR_112)
/SW6: SW11.7, U11.75 (IOR_111)
/SW7: SW11.8, U11.74 (IOR_110)
/TXD0: J11.8 (GPIO14)
/VBATT_DIV: J20.1, R25.1
/VB_LIM: C77.1, C78.1, D12.1 (K), J14.1, J27.1, L14.1, U26.4 (~SHDN), U26.5 (VIN), U27.3 (VO)
/~ADC_CS: U11.118 (IOT_177), U16.10 (~CS~/SHDN)
/~CRESET~: R21.1, RN14.3 (R3.1), U11.66 (~CRESET)
GND: C11.2, C16.2, C17.2, C18.2, C19.2, C20.2, C21.2, C22.2, C23.2, C24.2, C25.2, C26.2, C27.2, C28.2, C29.2, C30.2, C32.2, C34.2, C36.2, C37.2, C38.2, C39.2, C40.2, C41.2, C42.2, C43.2, C44.2, C45.2, C46.2, C47.2, C48.2, C50.2, C51.2, C52.2, C53.2, C54.2, C55.2, C56.2, C57.2, C58.2, C59.2, C61.2, C62.2, C63.2, C64.2, C66.2, C67.2, C68.2, C69.2, C70.2, C71.2, C72.2, C73.2, C74.2, C75.2, C76.2, C77.2, C78.2, C79.2, D0.1 (K), D1.1 (K), D2.1 (K), D3.1 (K), D4.1 (K), D5.1 (K), D6.1 (K), D7.1 (K), D22.1 (K), J11.6 (GND), J11.9 (GND), J11.14 (GND), J11.20 (GND), J11.25 (GND), J11.30 (GND), J11.34 (GND), J11.39 (GND), J12.1, J19.1, J19.2, J19.3, J19.4, J19.5, J19.6, J19.7, J19.8, J19.9, J19.10, J22.1, J22.2, J22.3, J22.4, J22.5, J22.6, J22.7, J22.8, J26.1, J26.2, J26.3, J26.4, J26.5, J26.6, J26.7, J26.8, J30.1, J30.2, J30.3, J30.4, J30.5, J30.6, J30.7, J30.8, J30.9, J30.10, J30.11, J30.12, J30.13, J30.14, J30.15, J30.16, J32.1, J32.2, J32.3, J32.4, J32.5, J32.6, J32.7, J32.8, J35.1, NT1.1, Q11.9 (GND), Q12.2 (S), Q13.2 (S), R13.1, R15.1, R22.1, R37.2, R39.2, R40.2, R41.2, R42.2, R43.2, R44.2, R45.2, R46.2, R48.2, R50.2, R52.2, RN15.1 (R1.1), RN15.2 (R2.1), RN15.3 (R3.1), RN15.4 (R4.1), RN15.5 (R5.1), RN15.6 (R6.1), RN15.7 (R7.1), RN15.8 (R8.1), S11.3, S12.3, SW11.9, SW11.10, SW11.11, SW11.12, SW11.13, SW11.14, SW11.15, SW11.16, U11.5 (GND), U11.13 (GND), U11.14 (GND), U11.59 (GND), U11.69 (GND), U11.86 (GND), U11.103 (GND), U11.132 (GND), U11.140 (GND), U12.10 (GND), U12.19 (~OE), U13.10 (GND), U13.19 (~OE), U14.10 (GND), U14.19 (~OE), U15.4 (GND), U16.9 (DGND), U16.14 (AGND), U17.1 (GND), U18.1 (GND), U19.1 (GND), U20.4 (GND), U21.1 (DIR), U21.10 (GND), U21.19 (~OE), U22.1 (DIR), U22.10 (GND), U22.19 (~OE), U23.10 (GND), U23.19 (~OE), U24.1 (DIR), U24.10 (GND), U24.19 (~OE), U25.4 (GND), U26.2 (GND), U27.2 (GND), Y11.2 (GND)
unnamed: C11.1, D11.1 (K), U11.108 (VPP_2V5)
unnamed: C12.1, C13.1, R11.2, U11.54 (VCCPLL0)
unnamed: C12.2, C13.2, U11.53 (GNDPLL0)
unnamed: C14.1, C15.1, R14.2, U11.126 (VCCPLL1)
unnamed: C14.2, C15.2, U11.127 (GNDPLL1)
unnamed: C31.1, U15.6 (BST)
unnamed: C31.2, L11.1, U15.5 (SW)
unnamed: C33.2, R47.2, R48.1, U15.1 (FB)
unnamed: C35.1, U20.6 (BST)
unnamed: C35.2, L12.1, U20.5 (SW)
unnamed: C36.1, R27.1, U16.15 (Vref)
unnamed: C38.1, R28.2, R39.1, U16.1 (CH0)
unnamed: C40.1, R29.2, R40.1, U16.2 (CH1)
unnamed: C41.1, R30.2, R41.1, U16.3 (CH2)
unnamed: C42.1, R31.2, R42.1, U16.4 (CH3)
unnamed: C43.1, R32.2, R43.1, U16.5 (CH4)
unnamed: C44.1, R33.2, R44.1, U16.6 (CH5)
unnamed: C45.1, R34.2, R45.1, U16.7 (CH6)
unnamed: C49.2, R49.2, R50.1, U20.1 (FB)
unnamed: C51.1, R35.2, R46.1, U16.8 (CH7)
unnamed: C60.1, U25.6 (BST)
unnamed: C60.2, L13.1, U25.5 (SW)
unnamed: C65.2, R37.1, R38.1, U25.1 (FB)
unnamed: D0.2 (A), RN11.16 (R1.2)
unnamed: D1.2 (A), RN11.15 (R2.2)
unnamed: D2.2 (A), RN11.14 (R3.2)
unnamed: D3.2 (A), RN11.13 (R4.2)
unnamed: D4.2 (A), RN11.12 (R5.2)
unnamed: D5.2 (A), RN11.11 (R6.2)
unnamed: D6.2 (A), RN11.10 (R7.2)
unnamed: D7.2 (A), RN11.9 (R8.2)
unnamed: D12.2 (A), J27.2, Q13.3 (D)
unnamed: D20.2 (A), L14.2, U26.1 (SW)
unnamed: D21.1 (K), F12.2
unnamed: D21.2 (A), J35.2
unnamed: D22.2 (A), R53.1
unnamed: J14.2, Q12.3 (D)
unnamed: J20.2, R28.1
unnamed: J20.3, R29.1
unnamed: J20.4, R30.1
unnamed: J20.5, R31.1
unnamed: J20.6, R32.1
unnamed: J20.7, R33.1
unnamed: J20.8, R34.1
unnamed: J20.9, R35.1
unnamed: NT1.2, U14.2 (A1), U14.3 (A2), U14.4 (A3), U14.5 (A4)
unnamed: Q12.1 (G), R54.1
unnamed: Q13.1 (G), R12.1
unnamed: R36.1, R38.2, SW1.1
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

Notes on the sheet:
Copyright (C) 2020 John Winans This documentation describes Open Hardware and is licensed under the CERN OHL v. 1.2. You may redistribute and modify this documentation under the terms of the CERN OHL v.1.2. (http://ohwr.org/cernohl). This documentation is distributed WITHOUT ANY EXPRESS OR IMPLIED 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
https://github.com/johnwinans/2060-ORIO2
I2C (Breakout of the PI I2C pins w/3.3v power & pull ups)
Battery Voltage Monitor
Quadrature Input
ADC
Solenoid Driver (500mA max across all solenoids)
5V Tolerant DOUT
5V Tolerant DIN
12V Battery
10A
User Buttons
User LEDs
User Switches
6V @ 3A
5V Tolerant Quadrature Input
PWM output
closed = 3.3V open = 5V
FPGA DIrect IO
24V @ 500mA Boost Regulator
Power Indicator
RS Light
(* 6V with ADC divider for raw voltage)
(* .006444 as drawn for raw voltage)
5V @ 3A
Current Limiter
3.3V or 5V @ 3A
Compressor Relay

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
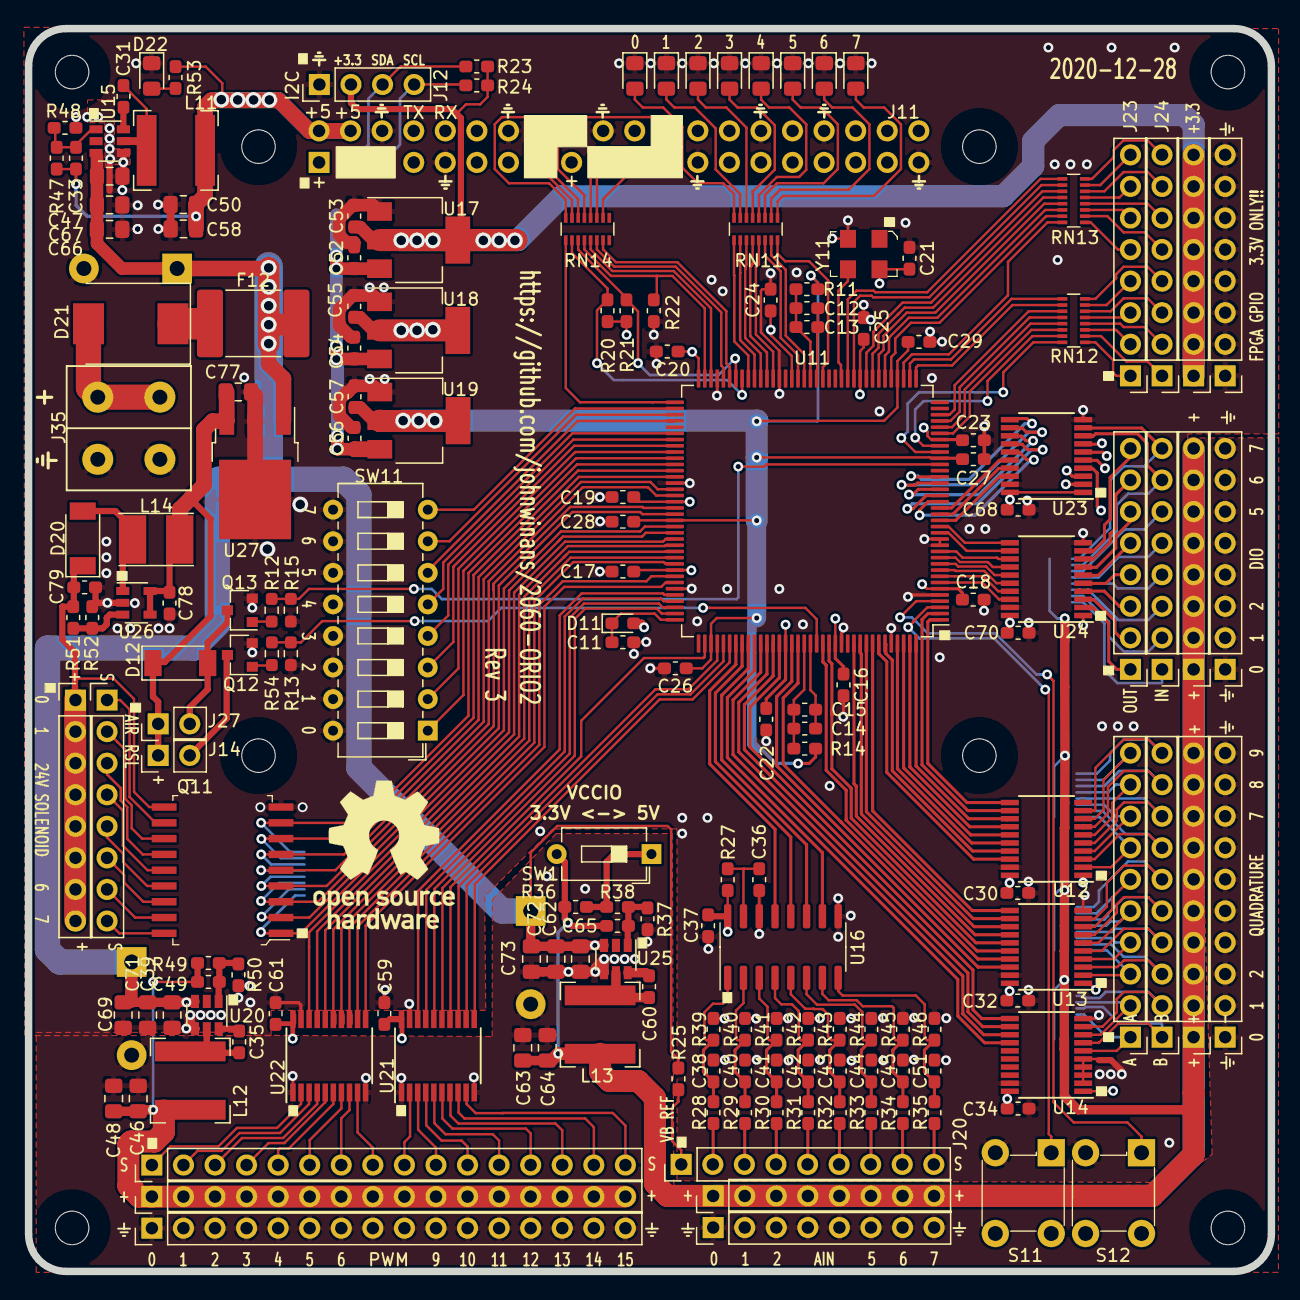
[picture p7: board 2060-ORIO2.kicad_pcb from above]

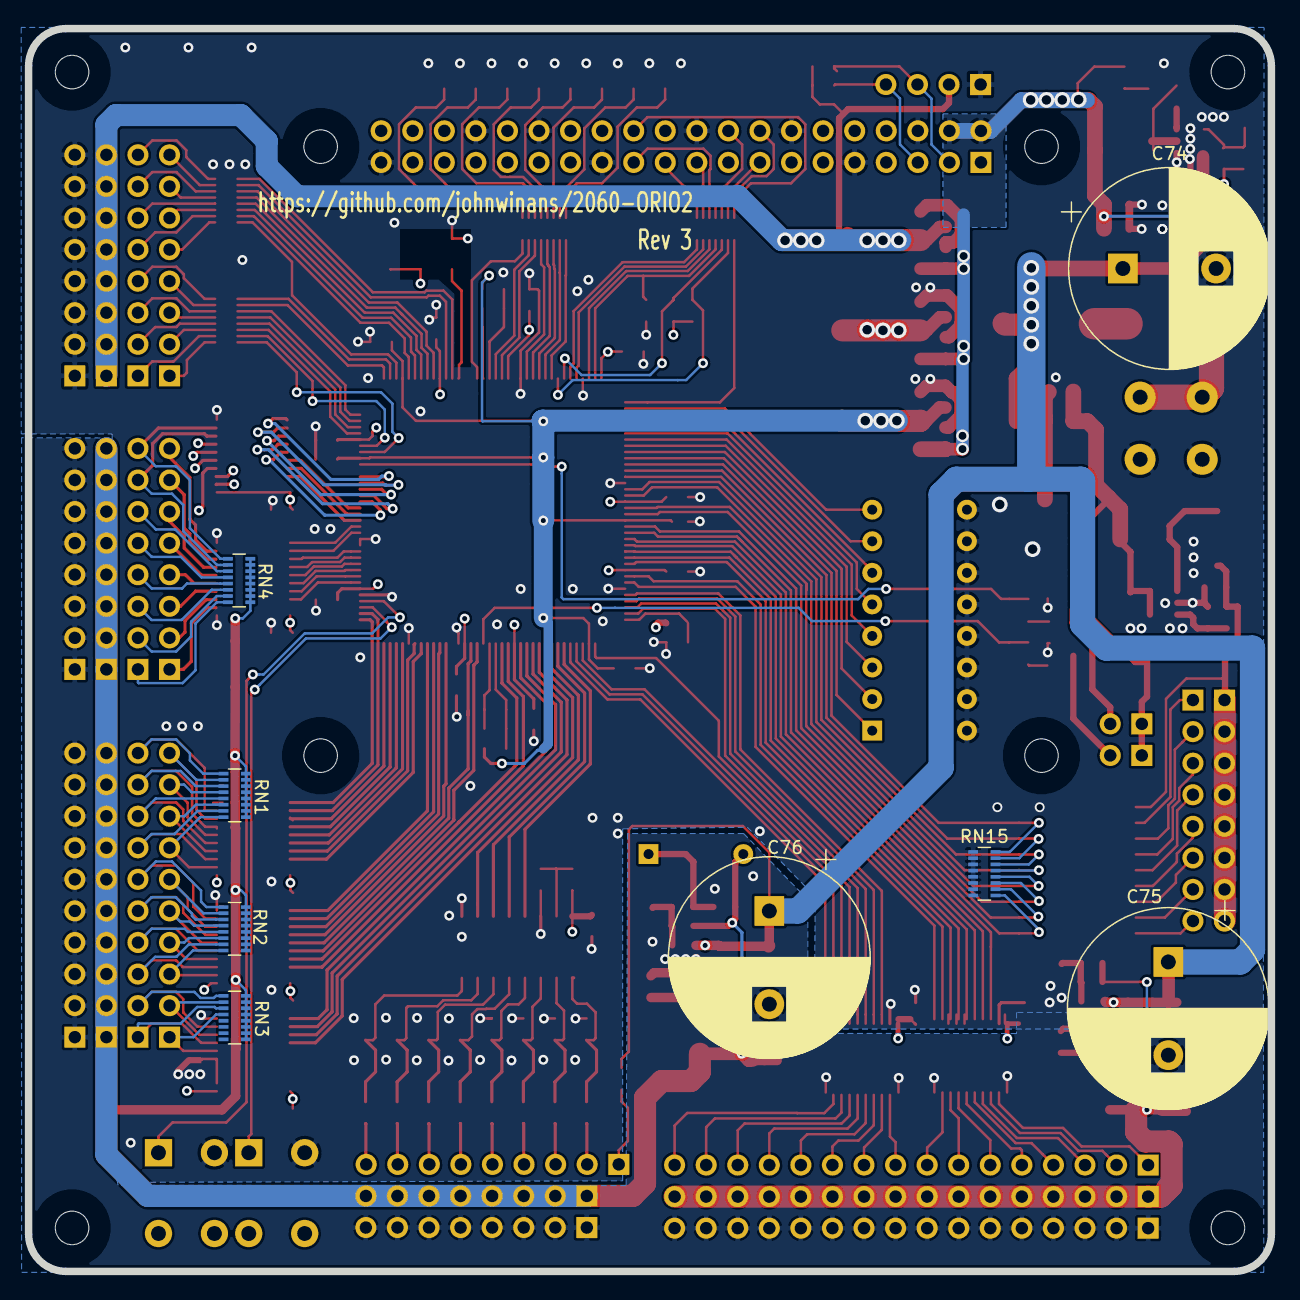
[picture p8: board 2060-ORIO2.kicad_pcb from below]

Board: 4 copper layers, 100.0 x 100.0 mm, 195 parts (8 on the bottom side), 254 nets.

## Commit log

2020-06-05 Checkpoint draft.
    [2060-ORIO2.kicad_pcb, 2060-ORIO2.sch]
2020-06-08 Add link to PCB image.
2020-06-08 Dev checkpoint (first version passing DRC)
    [2060-ORIO2.kicad_pcb, 2060-ORIO2.sch]
2020-06-09 Part value & BOM cleanup.
    [2060-ORIO2.kicad_pcb, 2060-ORIO2.sch]
2020-06-10 Added a pdf of the schematic.
2020-06-10 Checkpoint before re-annotate.
    [2060-ORIO2.kicad_pcb]
2020-06-10 Re-annotate schematic, clean silks, add NT1.
    [2060-ORIO2.kicad_pcb, 2060-ORIO2.sch]
2020-06-10 Added power LED & GND plane vias.
    [2060-ORIO2.kicad_pcb, 2060-ORIO2.sch]
2020-06-11 Fuses, 4-layer, RSL, 86 the Solenoid GND,
    [2060-ORIO2.kicad_pcb, 2060-ORIO2.sch]
2020-06-13 Added pul;lup resistors on DIN level shifters.
    [2060-ORIO2.kicad_pcb, 2060-ORIO2.sch]
2020-06-14 Cosmetic silkscreen changes.
    [2060-ORIO2.kicad_pcb]
2020-06-17 Final BOM review & corrections to values.
    [2060-ORIO2.sch]
2020-06-26 Change ADC ref voltage resistor to 100 ohms.
    [2060-ORIO2.sch]
2020-07-18 Change regulators & add current limiters.
    [2060-ORIO2.kicad_pcb, 2060-ORIO2.sch]
2020-07-20 Change +BATT voltage divider to /6.
    [2060-ORIO2.kicad_pcb, 2060-ORIO2.sch]
2020-07-20 Adjust solenoid connector position.
    [2060-ORIO2.kicad_pcb]
2020-07-20 Version 2.1 As ordered from JLCPCB.
    [2060-ORIO2-B_Cu.gbr, 2060-ORIO2-B_Mask.gbr, 2060-ORIO2-B_SilkS.gbr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]
2020-07-29 Replace AOZ2151TQI-19 regulators with AP63300WU-7
    [2060-ORIO2.kicad_pcb, 2060-ORIO2.sch]
2020-07-29 Remove Rev 1 gerbers.
    [2060-ORIO2-B_Cu.gbr, 2060-ORIO2-B_Mask.gbr, 2060-ORIO2-B_SilkS.gbr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]
2020-07-30 Revision 2 as ordered from JLCPCB
    [2060-ORIO2-B_Cu.gbr, 2060-ORIO2-B_Mask.gbr, 2060-ORIO2-B_SilkS.gbr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]
2020-12-29 Move the PI connector, add filter caps, & tweak current limiter.
    [2060-ORIO2-B_Cu.gbr, 2060-ORIO2-B_Mask.gbr, 2060-ORIO2-B_SilkS.gbr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]
2020-12-29 Change 12V LDO, header & cap clearance
    [2060-ORIO2-B_Cu.gbr, 2060-ORIO2-B_Mask.gbr, 2060-ORIO2-B_SilkS.gbr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]
